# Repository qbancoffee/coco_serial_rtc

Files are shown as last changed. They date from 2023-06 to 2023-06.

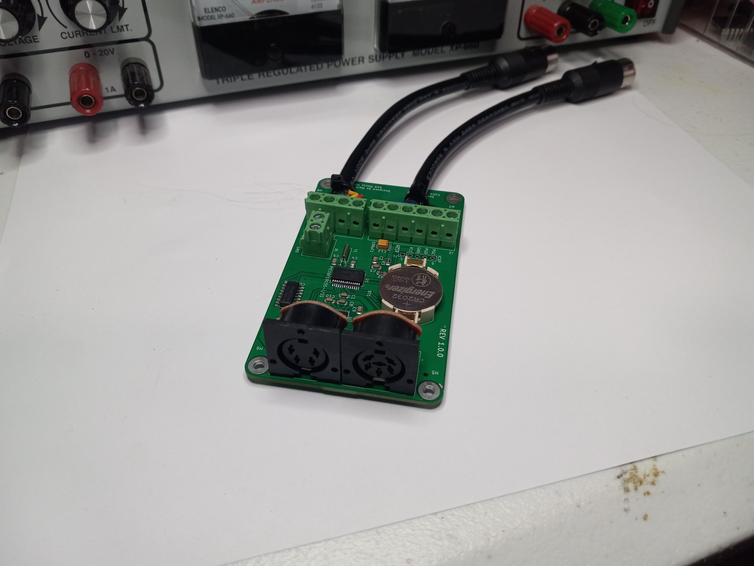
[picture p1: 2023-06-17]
images/coco_serial_rtc_assembled_3.jpg

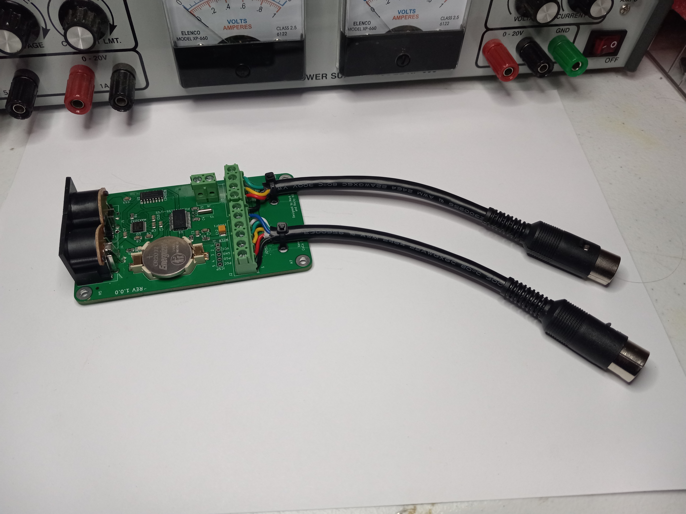
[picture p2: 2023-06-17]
images/coco_serial_rtc_assembled_2.jpg

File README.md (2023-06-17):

# coco_serial_rtc
An external Real Time Clock circuit (RTC) for the Tandy CoCo.

This is a realtime clock prototype for the Tandy CoCo. The board connects to the CoCo's bit banger serial port via a male DIN connector pigtail.
Whith the appropriate commands from the CoCo, one can get the date/time or one can set the date/time. The rest of the time it just sits in place and works as a serial passthrough so that you can still connect other serial devices to the CoCo. The other serial devices can connect to the onboard DIN connector. The board requires +5V DC and can be powered from the CoCo's joystick port or one can provide the voltage to a 2 pin terminal strip. The board also serves a passthrough when using the joystick port.

The board was designed using KiCAD 6 and the firmware was written in C and compiled with the [CCS C Compiler](https://www.ccsinfo.com/compilers.php).

## CoCo Serial RTC
- [Schematic](coco_serial_rtc_schematic.pdf)
- [Rendered Image](images/coco_serial_rtc_top.png)
- [Picture 1](images/coco_serial_rtc.jpg)
- [Picture 2](images/coco_serial_rtc_assembled_1.jpg)
- [Picture 3](images/coco_serial_rtc_assembled_2.jpg)
- [Picture 4](images/coco_serial_rtc_assembled_3.jpg)

## How it works
Add stuff here.

### Current status
- [x] Ordered
- [x] Assembled
- [x] Testing

The board is still in the prototype stage but so far things are looking good.

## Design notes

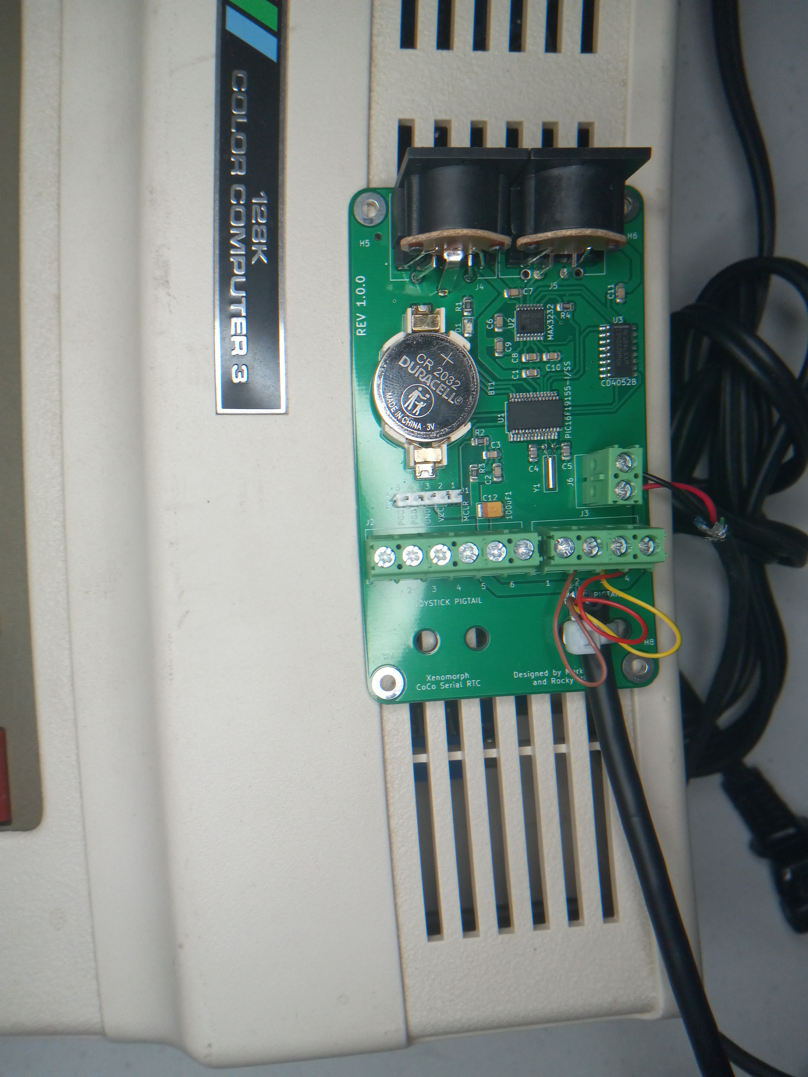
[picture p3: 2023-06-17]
images/coco_serial_rtc.jpg

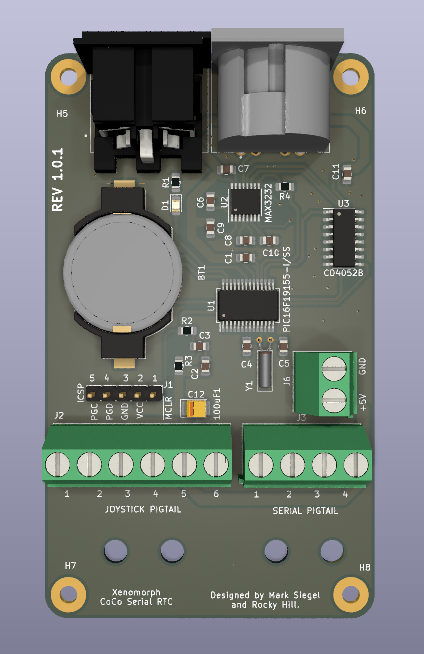
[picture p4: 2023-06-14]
images/coco_serial_rtc_top.png

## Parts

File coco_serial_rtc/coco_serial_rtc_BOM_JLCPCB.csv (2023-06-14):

Qty | Designator | Footprint | Vendor | Vendor part# | Manufacturer part# | Value | LibPart | Datasheet | Manufacturer part# | Vendor | Vendor part# | manufacturer part# | vendor | vendor part#
1 | C12 | Capacitor_Tantalum_SMD:CP_EIA-3528-21_Kemet-B_Pad1.50x2.35mm_HandSolder | LCSC | C16133 | TAJB107K006RNJ | C_Polarized_Small | Device:C_Polarized_Small | https://datasheet.lcsc.com/lcsc/2111161030_Kyocera-AVX-TAJB107K006RNJ-_C16133.pdf | TAJB107K006RNJ | LCSC | C16133
1 | BT1 | Battery:BatteryHolder_Keystone_1058_1x2032 | LCSC | C964770 | BS-06-B4AA015 | CR2032 | Device:Battery_Cell | https://datasheet.lcsc.com/lcsc/2012311835_MYOUNG-BS-06-B4AA015_C964770.pdf | BS-06-B4AA015 | LCSC | C964770
9 | C1, C2, C3, C6, C7, C8, C9, C10, C11 | Capacitor_SMD:C_0805_2012Metric_Pad1.18x1.45mm_HandSolder | LCSC | C49678 | CC0805KRX7R9BB104 | .1uF | Device:C_Small | https://datasheet.lcsc.com/lcsc/1810101813_YAGEO-CC0805KRX7R9BB104_C49678.pdf | CC0805KRX7R9BB104 | LCSC | C49678
2 | C4, C5 | Capacitor_SMD:C_0805_2012Metric_Pad1.18x1.45mm_HandSolder | LCSC | C1804 | CL21C220JBANNNC | 22pF | Device:C_Small | https://datasheet.lcsc.com/lcsc/1810271113_Samsung-Electro-Mechanics-CL21C220JBANNNC_C1804.pdf | CL21C220JBANNNC | LCSC | C1804
1 | D1 | LED_SMD:LED_0805_2012Metric_Pad1.15x1.40mm_HandSolder | LCSC | C2296 | 17-21SUYC/TR8 | LED | Device:LED | https://datasheet.lcsc.com/lcsc/1806151129_Hubei-KENTO-Elec-17-21SUYC-TR8_C2296.pdf | 17-21SUYC/TR8 | LCSC | C2296
4 | H1, H2, H3, H4 | MountingHole:MountingHole_4mm |  | DNI | DNI | MountingHole | Mechanical:MountingHole | ~
4 | H5, H6, H7, H8 | MountingHole:MountingHole_3mm_Pad |  | DNI | DNI | MountingHole | Mechanical:MountingHole | ~
1 | J1 | Connector_PinHeader_2.54mm:PinHeader_1x05_P2.54mm_Vertical |  | DNI | DNI | ICSP | Connector:Conn_01x05_Male | ~
1 | J2 | TerminalBlock_Phoenix:TerminalBlock_Phoenix_MKDS-1,5-6_1x06_P5.00mm_Horizontal | digikey | DNI | DNI | joystick terminal | Connector:Screw_Terminal_01x06 | https://media.digikey.com/pdf/Data%20Sheets/Phoenix%20Contact%20PDFs/1935161.pdf | 1935161 | digikey | 277-1667-ND
1 | J3 | TerminalBlock_Phoenix:TerminalBlock_Phoenix_MKDS-1,5-4_1x04_P5.00mm_Horizontal | digikey | DNI | DNI | serial terminal | Connector:Screw_Terminal_01x04 | https://media.digikey.com/pdf/Data%20Sheets/Phoenix%20Contact%20PDFs/1935161.pdf | 1935161 | digikey | 277-1667-ND
1 | J4 | serial_rtc.kicad:CUI_SDS-60J | digikey | DNI | DNI | DIN-6 | serial_rtc:DIN-6-Connector | http://www.mouser.com/ds/2/18/40_c091_abd_e-75918.pdf | SDS-60J | digikey | CP-2360-ND
1 | J5 | serial_rtc.kicad:CUI_SDS-40J | digikey | DNI | DNI | DIN-4 | serial_rtc:DIN-4-Connector | https://www.cuidevices.com/product/resource/digikeypdf/sds-j.pdf | SDS-40J | digikey | CP-2340-ND
1 | J6 | TerminalBlock_Phoenix:TerminalBlock_Phoenix_MKDS-1,5-2_1x02_P5.00mm_Horizontal | digikey | DNI | DNI | power terminal | Connector:Screw_Terminal_01x02 | https://media.digikey.com/pdf/Data%20Sheets/Phoenix%20Contact%20PDFs/1935161.pdf | 1935161 | digikey | 277-1667-ND
1 | R1 | Resistor_SMD:R_0805_2012Metric_Pad1.20x1.40mm_HandSolder | LCSC |  |  | 330 | Device:R_Small_US | ~ |  | LCSC
1 | R2 | Resistor_SMD:R_0805_2012Metric_Pad1.20x1.40mm_HandSolder | LCSC | C17540 | 0805W8F2000T5E | 200 | Device:R_Small_US | https://datasheet.lcsc.com/lcsc/2206010200_UNI-ROYAL-Uniroyal-Elec-0805W8F2000T5E_C17540.pdf | 0805W8F2000T5E | LCSC | C17540
1 | R3 | Resistor_SMD:R_0805_2012Metric_Pad1.20x1.40mm_HandSolder | LCSC | C17414 | 0805W8F1002T5E | 10K | Device:R_Small_US | https://datasheet.lcsc.com/lcsc/2206010216_UNI-ROYAL-Uniroyal-Elec-0805W8F1501T5E_C4310.pdf | 0805W8F1002T5E | LCSC | C17414
1 | R4 | Resistor_SMD:R_0805_2012Metric_Pad1.20x1.40mm_HandSolder | LCSC | C17710 | 0805W8F4700T5E | 470 | Device:R_Small_US | https://datasheet.lcsc.com/lcsc/2206010200_UNI-ROYAL-Uniroyal-Elec-0805W8F4700T5E_C17710.pdf | 0805W8F4700T5E | LCSC | C17710
1 | U1 | Package_SO:SSOP-28_5.3x10.2mm_P0.65mm | digikey | DNI | DNI | PIC16F19155-I/SS | serial_rtc:PIC16F19155-I{slash}SS | https://ww1.microchip.com/downloads/en/DeviceDoc/PIC16LF19155-56-75-76-85-86-Data-Sheet-40001923B.pdf | PIC16F19155-I/SS | digikey | PIC16F19155-I/SS-ND
1 | U2 | Package_SO:TSSOP-16-1EP_4.4x5mm_P0.65mm | LCSC | C19767 | MAX3232EUE+T | MAX3232 | Interface_UART:MAX3232 | http://www.ti.com/general/docs/suppproductinfo.tsp?distId=10 | MAX3232EUE+T | LCSC | C19767
1 | U3 | Package_SO:SOIC-16_3.9x9.9mm_P1.27mm | LCSC | C6521 | CD4052BM96 | CD4052B | Analog_Switch:CD4052B | http://www.ti.com/lit/ds/symlink/cd4052b.pdf | CD4052BM96 | LCSC | C6521
1 | Y1 | Crystal:Crystal_C26-LF_D2.1mm_L6.5mm_Horizontal | digikey | DNI | DNI | 32.768kHz | Device:Crystal | http://cfd.citizen.co.jp/cms/cfd/pdf/english/CFS-206_CFS-145_E.pdf |  |  |  | CFS-20632768DZBB | digikey | 300-8301-ND

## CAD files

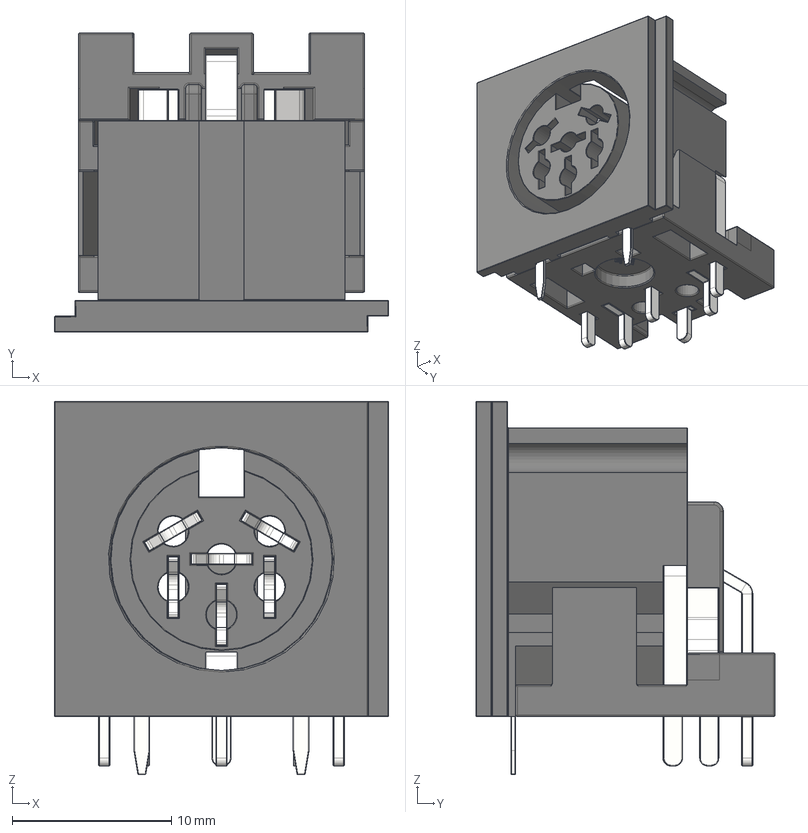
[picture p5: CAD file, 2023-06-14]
coco_serial_rtc/3d_models/DIN-6.step
21.0 x 18.8 x 23.4 mm
Baseplate IEC
Pin3
Pin4_2
Pin5_1
Pin6
Gnd pins
Housing

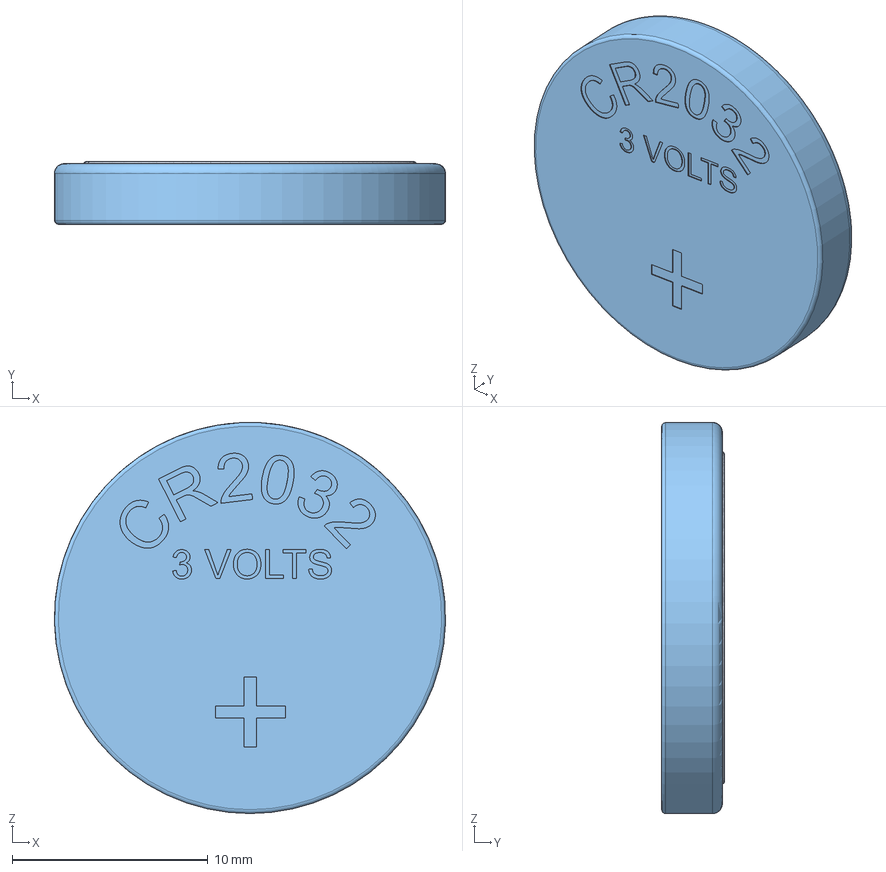
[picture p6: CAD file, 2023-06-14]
coco_serial_rtc/3d_models/CR2032-50004LC.stp
20.0 x 3.20 x 20.0 mm

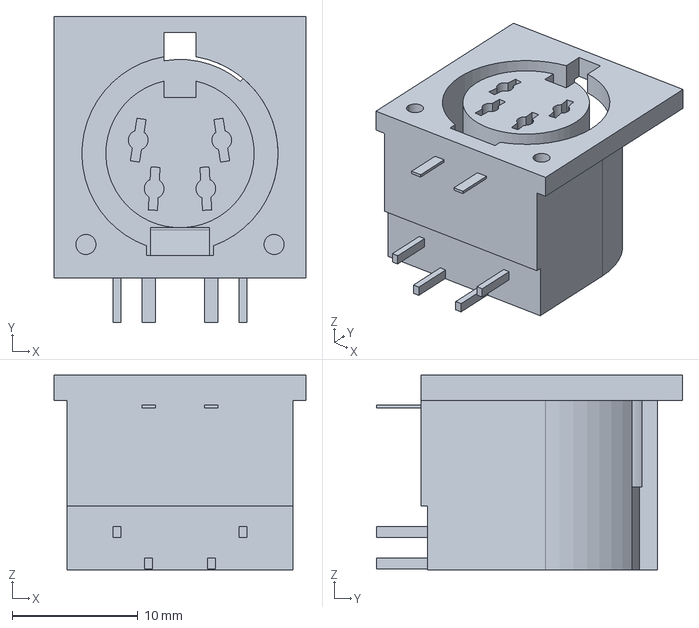
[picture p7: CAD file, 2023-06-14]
coco_serial_rtc/3d_models/DIN-4.stp
20.1 x 24.4 x 15.5 mm

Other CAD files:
coco_serial_rtc/Unnamed-coco_serial_rtc.stl

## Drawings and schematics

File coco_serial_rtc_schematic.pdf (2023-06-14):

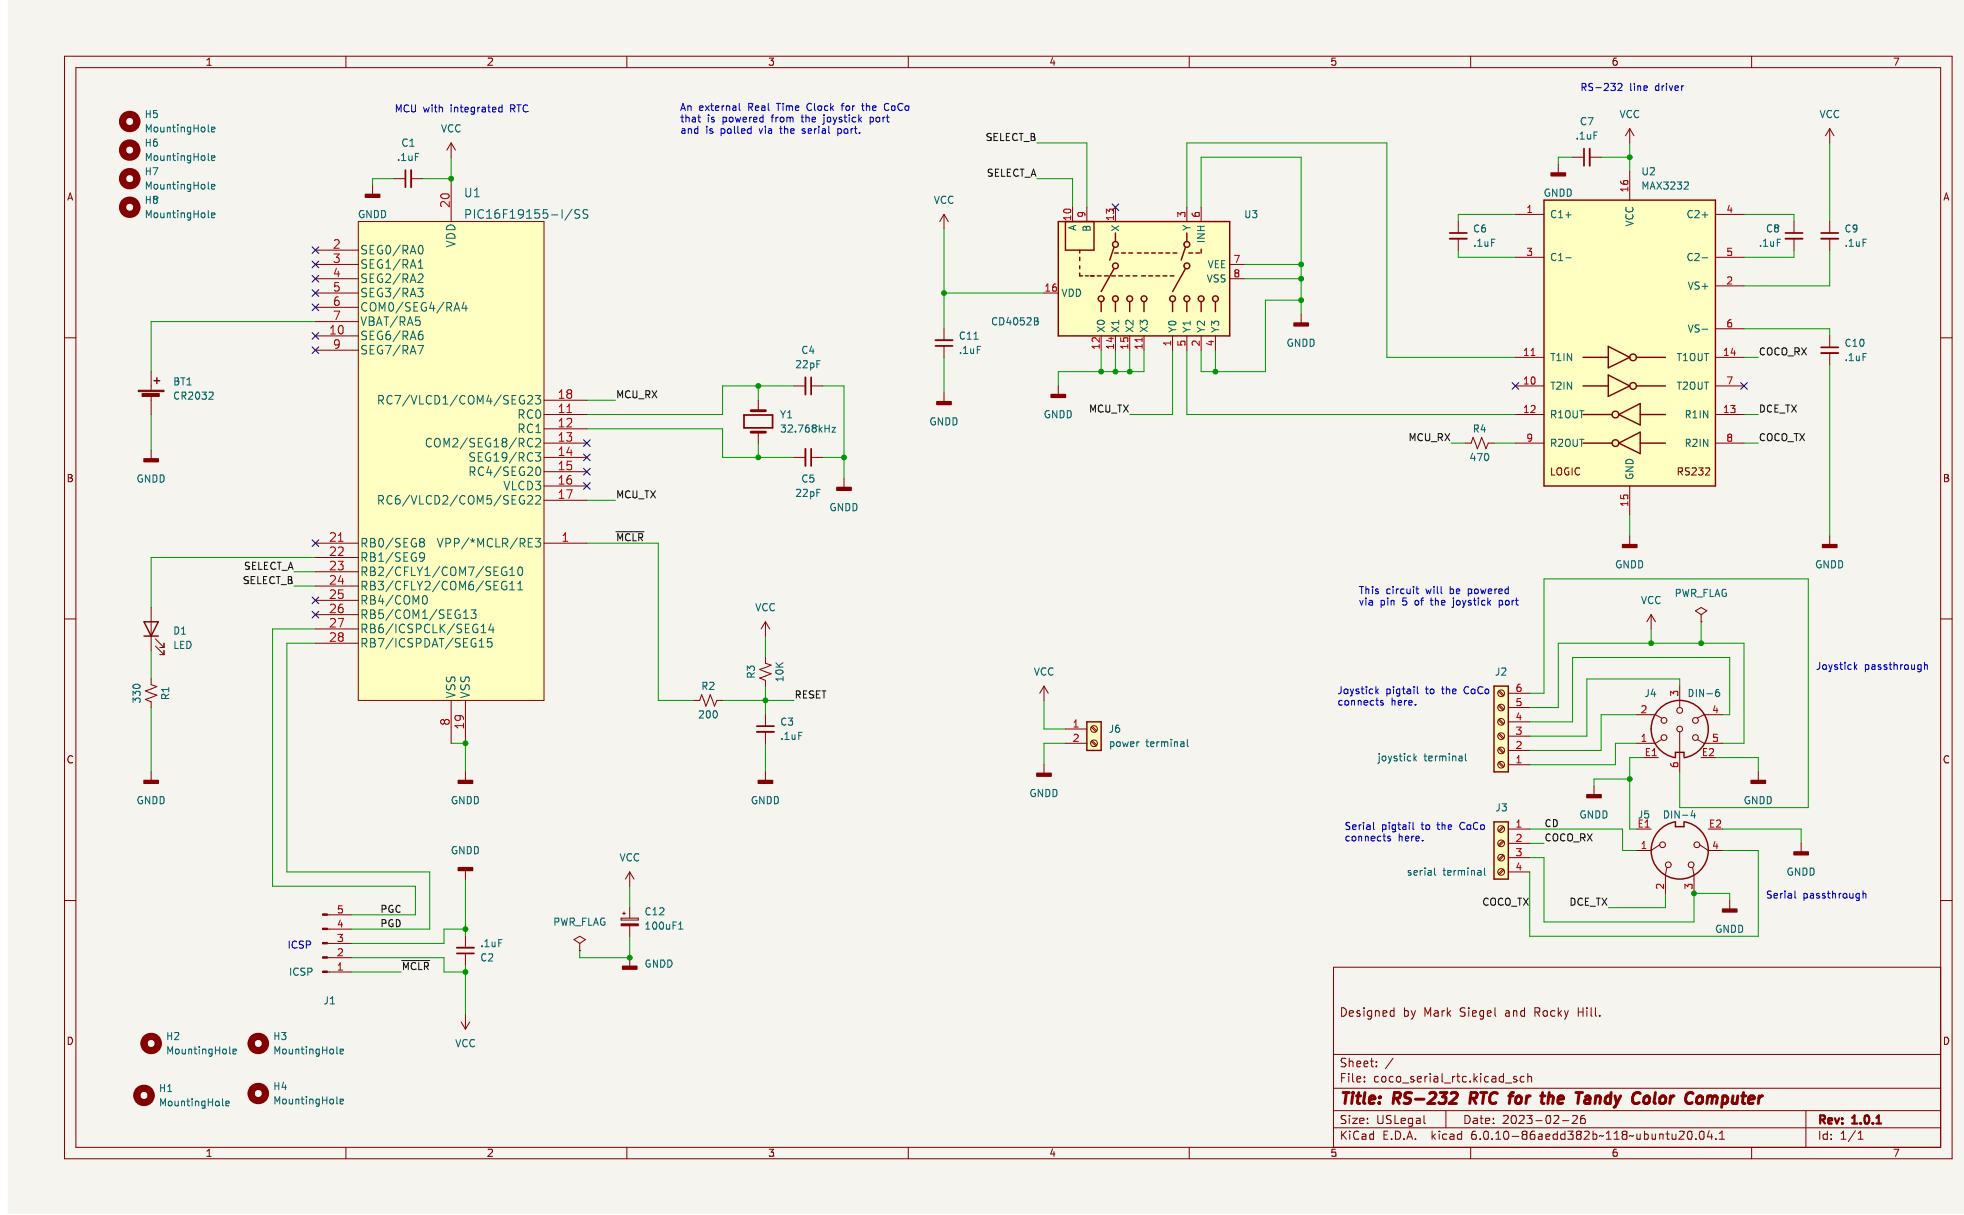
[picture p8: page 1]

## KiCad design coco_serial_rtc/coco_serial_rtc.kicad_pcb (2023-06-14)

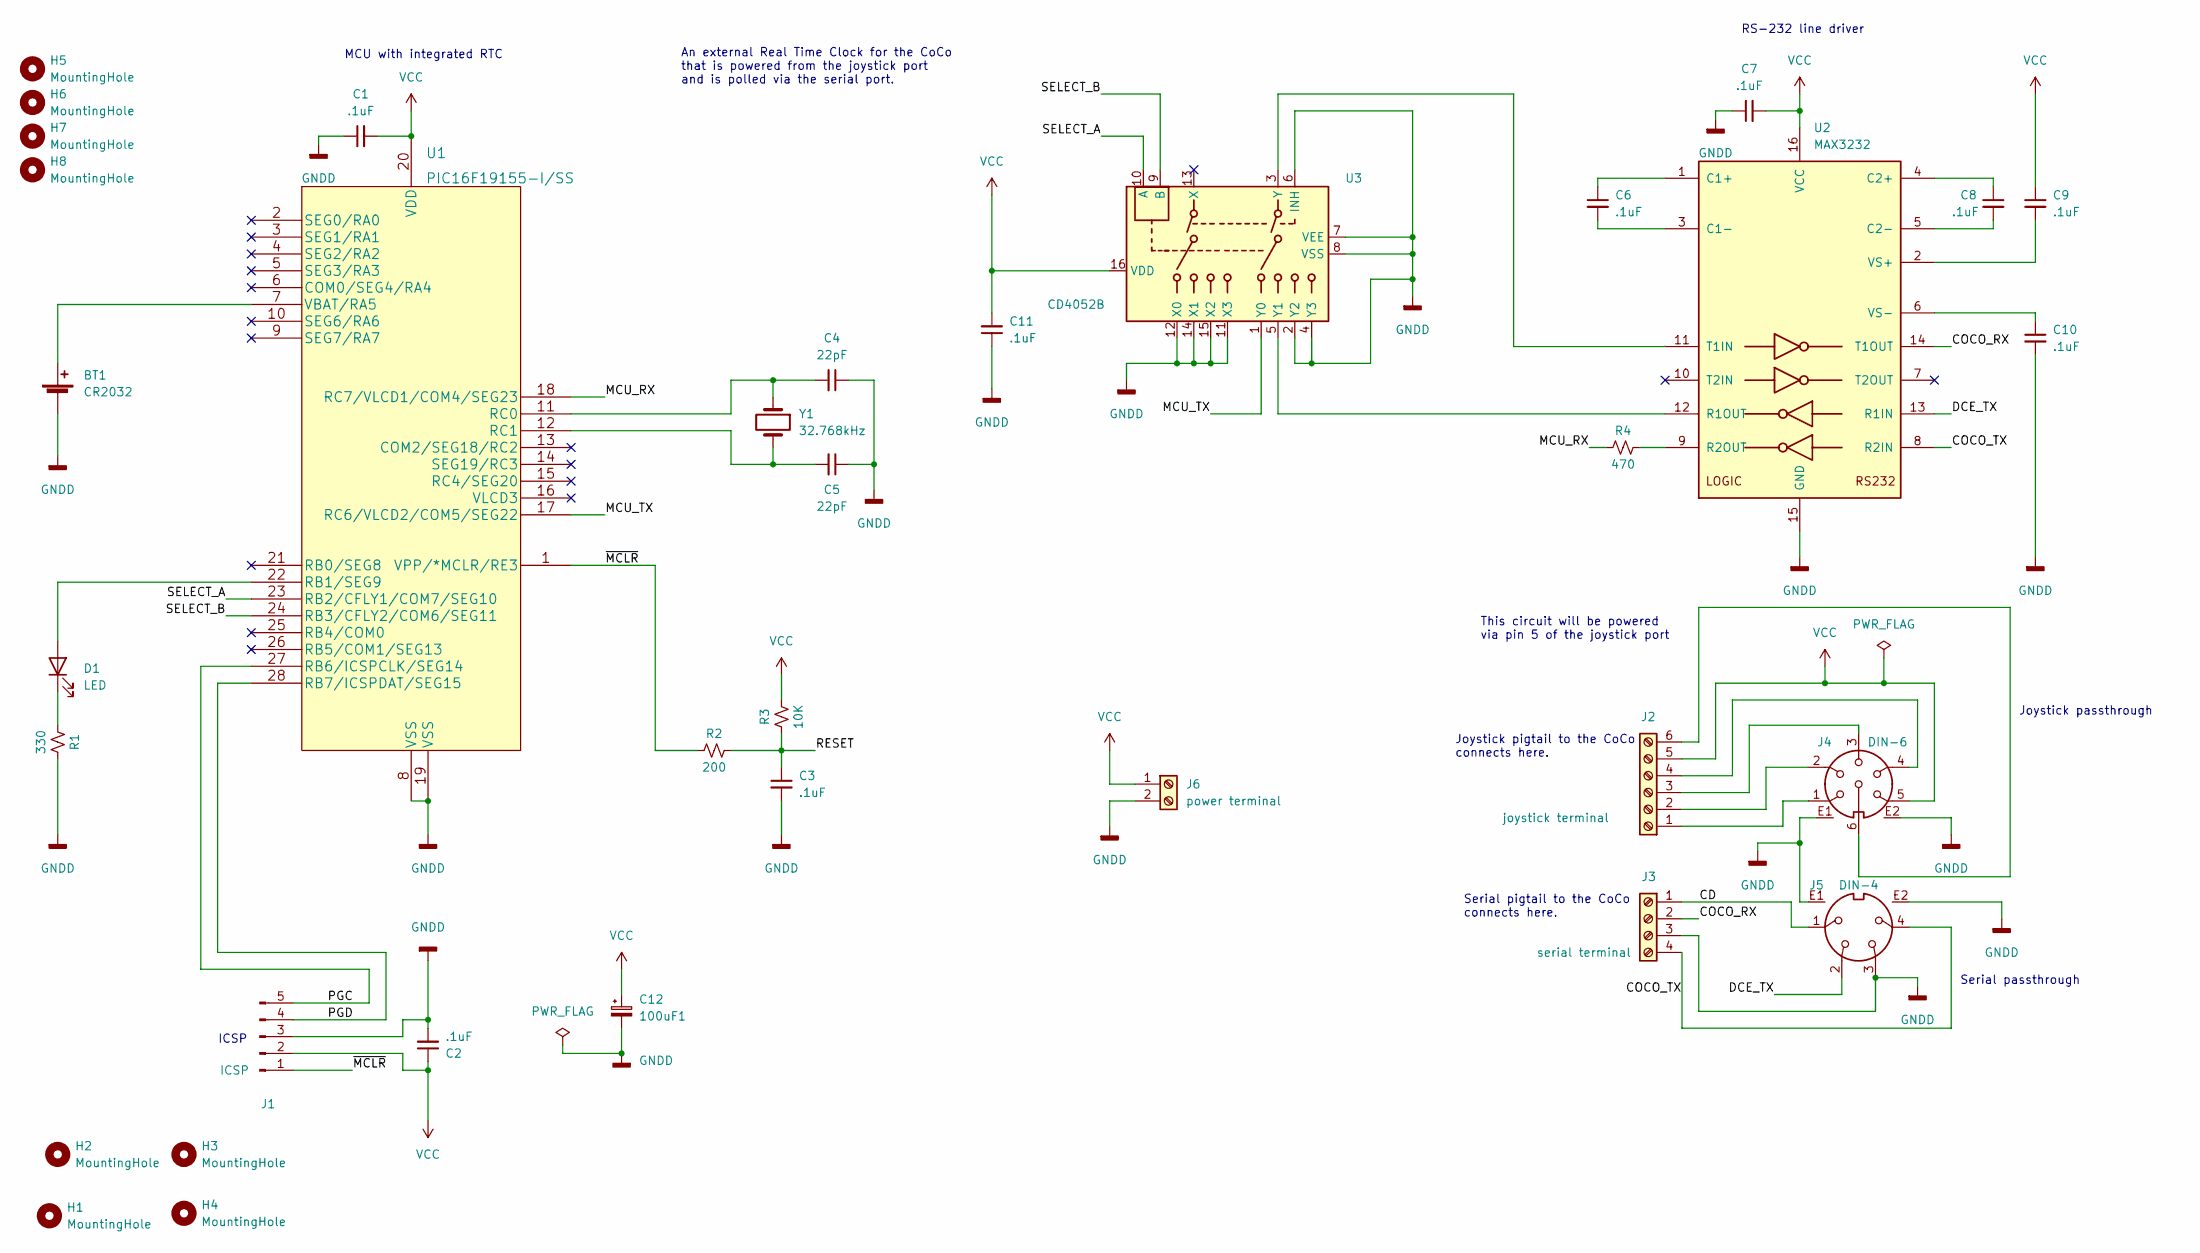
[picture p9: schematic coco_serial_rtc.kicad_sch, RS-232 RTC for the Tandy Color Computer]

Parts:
BT1: CR2032; BatteryHolder_Keystone_1058_1x2032; Manufacturer part# BS-06-B4AA015
C1, C2, C3, C6, C7, C8, C9, C10, C11: .1uF; C_0805_2012Metric_Pad1.18x1.45mm_HandSolder; Manufacturer part# CC0805KRX7R9BB104
C4, C5: 22pF; C_0805_2012Metric_Pad1.18x1.45mm_HandSolder; Manufacturer part# CL21C220JBANNNC
C12: 100uF1; CP_EIA-3528-21_Kemet-B_Pad1.50x2.35mm_HandSolder; Manufacturer part# TAJB107K006RNJ
D1: LED; LED_0805_2012Metric_Pad1.15x1.40mm_HandSolder; Manufacturer part# 17-21SUYC/TR8
H1, H2, H3, H4: MountingHole; MountingHole_4mm
H5, H6, H7, H8: MountingHole; MountingHole_3mm_Pad
J1: ICSP; PinHeader_1x05_P2.54mm_Vertical
J2: joystick terminal; TerminalBlock_Phoenix_MKDS-1,5-6_1x06_P5.00mm_Horizontal; Manufacturer part# 1935161
J3: serial terminal; TerminalBlock_Phoenix_MKDS-1,5-4_1x04_P5.00mm_Horizontal; Manufacturer part# 1935161
J4: DIN-6; CUI_SDS-60J; Manufacturer part# SDS-60J
J5: DIN-4; CUI_SDS-40J; Manufacturer part# SDS-40J
J6: power terminal; TerminalBlock_Phoenix_MKDS-1,5-2_1x02_P5.00mm_Horizontal; Manufacturer part# 1935161
R1: 330; R_0805_2012Metric_Pad1.20x1.40mm_HandSolder
R2: 200; R_0805_2012Metric_Pad1.20x1.40mm_HandSolder; Manufacturer part# 0805W8F2000T5E
R3: 10K; R_0805_2012Metric_Pad1.20x1.40mm_HandSolder; Manufacturer part# 0805W8F1002T5E
R4: 470; R_0805_2012Metric_Pad1.20x1.40mm_HandSolder; Manufacturer part# 0805W8F4700T5E
U1: PIC16F19155-I/SS; SSOP-28_5.3x10.2mm_P0.65mm; Manufacturer part# PIC16F19155-I/SS
U2: MAX3232; TSSOP-16-1EP_4.4x5mm_P0.65mm; Manufacturer part# MAX3232EUE+T
U3: CD4052B; SOIC-16_3.9x9.9mm_P1.27mm; Manufacturer part# CD4052BM96
Y1: 32.768kHz; Crystal_C26-LF_D2.1mm_L6.5mm_Horizontal; Manufacturer part# CFS-20632768DZBB

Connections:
/CD: J3.1, J5.1
/COCO_RX: J3.2, U2.14 (T1OUT)
/COCO_TX: J3.4, J5.4, U2.8 (R2IN)
/DCE_TX: J5.2, U2.13 (R1IN)
/MCU_RX: R4.1, U1.18 (RC7/VLCD1/COM4/SEG23)
/MCU_TX: U1.17 (RC6/VLCD2/COM5/SEG22), U3.1 (Y0)
/PGC: J1.5, U1.27 (RB6/ICSPCLK/SEG14)
/PGD: J1.4, U1.28 (RB7/ICSPDAT/SEG15)
/RESET: C3.1, R2.2, R3.1
/SELECT_A: U1.23 (RB2/CFLY1/COM7/SEG10), U3.10 (A)
/SELECT_B: U1.24 (RB3/CFLY2/COM6/SEG11), U3.9 (B)
/~MCLR: J1.1, R2.1, U1.1 (VPP/*MCLR/RE3)
GNDD: BT1.2 (-), C1.1, C2.2, C3.2, C4.1, C5.1, C7.1, C10.2, C11.1, C12.2, J1.3, J3.3, J4.E1, J4.E2, J5.3, J5.E1, J5.E2, J6.2, R1.2, U1.8 (VSS), U1.19 (VSS), U2.15 (GND), U3.2 (Y2), U3.4 (Y3), U3.6 (INH), U3.7 (VEE), U3.8 (VSS), U3.11 (X3), U3.12 (X0), U3.14 (X1), U3.15 (X2)
unnamed: BT1.1 (+), U1.7 (VBAT/RA5)
unnamed: C4.2, U1.11 (RC0), Y1.1
unnamed: C5.2, U1.12 (RC1), Y1.2
unnamed: C6.1, U2.1 (C1+)
unnamed: C6.2, U2.3 (C1-)
unnamed: C8.1, U2.4 (C2+)
unnamed: C8.2, U2.5 (C2-)
unnamed: C9.2, U2.2 (VS+)
unnamed: C10.1, U2.6 (VS-)
unnamed: D1.1 (K), R1.1
unnamed: D1.2 (A), U1.22 (RB1/SEG9)
unnamed: J2.1, J4.1
unnamed: J2.2, J4.2
unnamed: J2.3, J4.3
unnamed: J2.4, J4.4
unnamed: J2.6, J4.6
unnamed: R4.2, U2.9 (R2OUT)
unnamed: U2.11 (T1IN), U3.3 (Y)
unnamed: U2.12 (R1OUT), U3.5 (Y1)
VCC: C1.2, C2.1, C7.2, C9.1, C11.2, C12.1, J1.2, J2.5, J4.5, J6.1, R3.2, U1.20 (VDD), U2.16 (VCC), U3.16 (VDD)

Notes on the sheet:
RS-232 line driver
An external Real Time Clock for the CoCo that is powered from the joystick port and is polled via the serial port.
Joystick passthrough
MCU with integrated RTC
Joystick pigtail to the CoCo connects here.
This circuit will be powered via pin 5 of the joystick port
ICSP
Serial pigtail to the CoCo connects here.
Serial passthrough

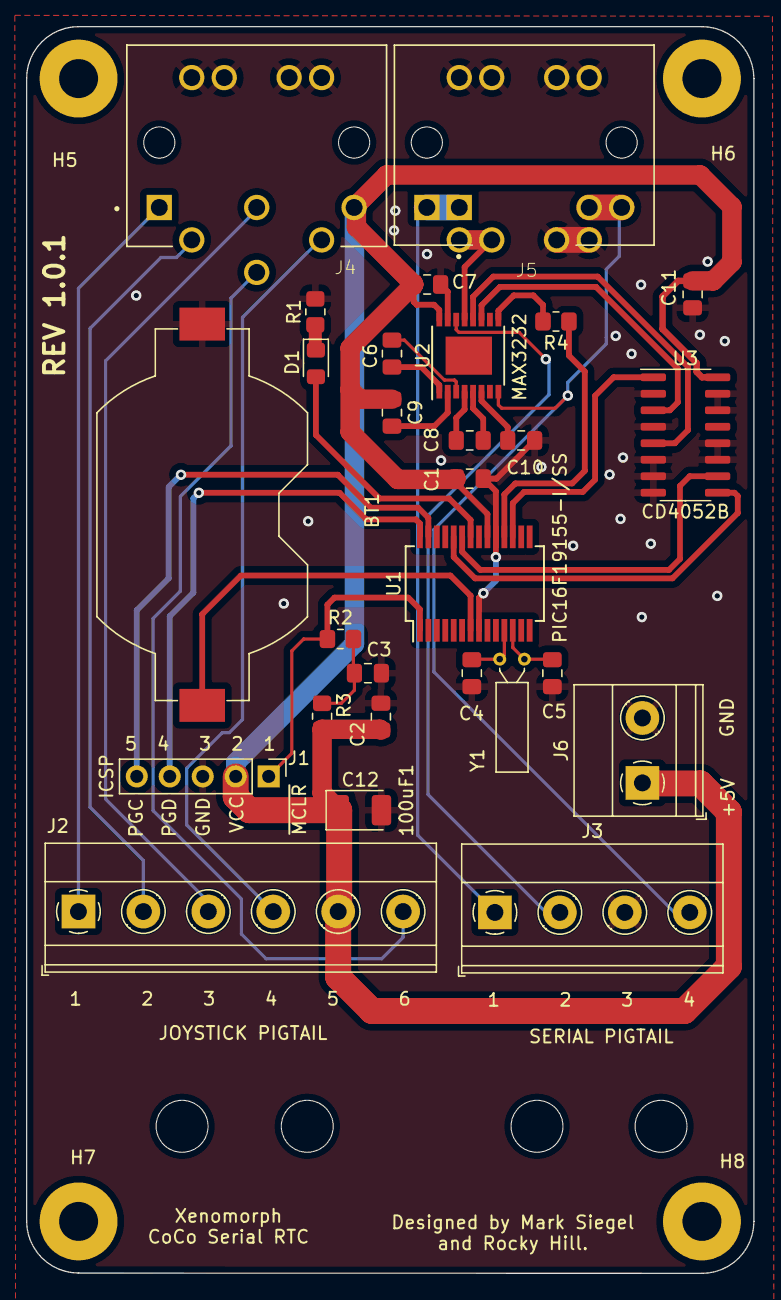
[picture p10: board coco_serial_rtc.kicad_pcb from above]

Board: 2 copper layers, 56.0 x 96.0 mm, 36 parts (0 on the bottom side), 33 nets.

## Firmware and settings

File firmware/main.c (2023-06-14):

//*************************************
//* <16F19155.h> processor
//* Date: 3/27/2023
//* Ver. 0.9
//* by M D Siegel
//*
//* Copyright 2023  M D SIEGEL
//* All Rights Reserved
//* Last updated 3/31/2023
//**************************************
  #include <main.h>
  #include <ctype.h>
  #include <stdio.h>
  #include <stddef.h>
  #include <stdlib.h>
  #include <string.h>

   //RTCC
  rtc_time_t wizardTempTime;
////////////////////////////////////////
// Pic 16F19155 Picdem 2 plus
// B1       LED
// B2       SELA
// B3       SELB
// C7       RX
// C6       TX
// B6       PGC
// B7       PGD
// E3       MCLR
// C0-C1    Crystal
///////////////////// Global Vars

static int cntdown;


char xstring1[20];
char xstring2[5];
//char xstring3[5];
char xstring4[7];
char pls[2] ="+";
char slp[6] ="SLEEP";
const char paramname[] [6]= {"VER","SDATE","STIME","RDT","MODE","PEEK","POKE","HELP",""""};

static int parsenum; //result of compair
static int parsetype; // operator
static int16 parseval; // val to set
static int split[8];
static char *pbuffer;
char rbuff[8];
static char compbuff[20];
static int buflen;
static char rs232buff[81];
static char rsreadbuff[81];
static int rsptr;
static int rtflag;
static int blenq;
static int16 aboo; //debug
char temp;

STATIC int16 ADC_BT;     // battery

///////////////////////Defines
#define LED PIN_B1   //LED
#define SELA PIN_B2
#define SELB PIN_B3
#define RX PIN_C7
#define TX PIN_C6

#define parseitm 9

#pin_select U1RX=PIN_C7

#use rs232(baud=1200,parity=N,xmit=PIN_C6,rcv=PIN_C7,bits=8,stream=DATA)

////////////// Functions
void copyright(void);
void  RTC_isr(void);
void  RDA_isr(void);
void  TIMER0_isr(void);

int read232(void);   // RS232
int is_rs232(void);
void clrprbuff(void);
void clrrsbuff(void);
int parseit(char * buf1,int clen);
char * strpiece(int pieceNum,int clen, char *buf1);
int compit(char *buf1, char *buf2, int clen);
int process(void);
void set_clock(void);
void read_clock(void);
void chan_sel(int chanx);
void updateADC();
void xsetDate();
void xsetTime();
void qsleep();
void xpoke();

////////////// code
#INT_TIMER0
void  TIMER0_isr(void) 
{
cntdown--;
   
   if(cntdown <= 0)
   { output_toggle(LED);
      cntdown = 60;
   }
    clear_interrupt(int_timer0);
}

#INT_RDA
void  RDA_isr(void) 
{
//! temp = fgetc(DATA);       //get char
//!       printf("*");
//!       rs232buff[rsptr++]=temp;  //inc buffer
//!       if (rsptr >= 79)          //max buffer
//!         {
//!            rsptr = 79;
//!         }
//!       if((temp == 0x0D))
//!       {
//!         temp = 0x0A;
//!         
//!       }
//!      
//!       if((temp == 0x0A))        //cr
//!         {
//!         
//!            if(rsptr >= 3)       //valid buffer process
//!            {
//!               rtflag = 1;
//!            }
//!            else
//!            {
//!               rsptr = 0;       //invalid buffer restart 
//!            }
//!          }
//!      
//! clear_interrupt(int_rda);
}

#INT_RTC
void  RTC_isr(void) 
{

}

void main()
{
    int16 wtmp, i, cmdsta;
    
   setup_adc_ports(0x3A);
   setup_adc(ADC_CLOCK_INTERNAL);
   setup_timer_0(RTCC_INTERNAL|RTCC_DIV_64|RTCC_8_BIT);      //2.0 ms overflow
   
   //RTCC
   setup_rtc(RTC_ENABLE|RTC_CLOCK_SOSC,0);
   enable_interrupts(INT_TIMER0);
   //enable_interrupts(INT_RDA);
   enable_interrupts(INT_RTC);
   enable_interrupts(GLOBAL);
   
   
   chan_sel(0);
   cntdown = 60;
   
   printf(" ***\n\r");
   printf("Coco RTC Command Processor Active \n\r");
   
   while(TRUE)
   {
      
      if(kbhit())
      {
      temp = fgetc(DATA);       //get char
       rs232buff[rsptr++]=temp;  //inc buffer
       if (rsptr >= 79)          //max buffer
         {
            rsptr = 79;
         }
       if((temp == 0x0D))
       {
         temp = 0x0A;
         
       }
      
       if((temp == 0x0A))        //cr
         {
         
            if(rsptr >= 3)       //valid buffer process
            {
               rtflag = 1;
            }
            else
            {
               rsptr = 0;       //invalid buffer restart 
            }
          }
      }
//////////////RS232 Process Terminal Loop
      if(is_rs232() == 1)
      {
       blenq = read232();
                           //printf("len %i buff %s \n\r",blenq,rs232buff );
      clrrsbuff();
        
      wtmp =  parseit(rsreadbuff, sizeof(rsreadbuff)); 
      pbuffer = strpiece(split[0], 20, rsreadbuff);   //Parse input
                           //printf("part1: %s \n\r",pbuffer);
     
     for(i=0;i<=parseitm;i++)                               //Compair to table
      { 
         sprintf(compbuff,"%s",paramname[i]);
         parsenum = strcmp(compbuff, pbuffer);
         if (parsenum==0)
         {
                           //printf("parse # %i \n\r",i);
            parsenum = i;
            break;
         }
         if(i == 19)
         {
         parsenum = i;
         }
                        //printf("parse # %i \n\r",i); 
      }
      ///////////////////
      pbuffer = 35;
      pbuffer = strpiece(split[1], 20, rsreadbuff);   //Parse function type
      if(*pbuffer == 35) //#
         {
         parsetype = 0;
         }
      if(*pbuffer == 63) //? return return
         {
         parsetype = 1;
         }
      if(*pbuffer == 61) //= set var
         {
         parsetype = 2;
         }
                        //printf("part2: %s \n\r",pbuffer);
      strcpy(xstring1,pbuffer);
                        //printf("parse type %i \n\r",parsetype);
      
      pbuffer = 0;
      pbuffer = strpiece(split[2], 20, rsreadbuff);  //Parse Parm
                     //parseval = atoi(pbuffer);
      
      if(parsetype == 2)
      {
     
      pbuffer = strpiece(split[2], 20, rsreadbuff);
      
                    //printf("str buff: %s \n\r",pbuffer);
      strcpy(rbuff,pbuffer);
      parseval = atol(rbuff);
      
                  //printf("part3: %Ld \n\r",parseval);
      }
      if(parsenum <= parseitm)
      {
                  //printf("parse # %i \n\r",parsenum);
      cmdsta = process(); //Process Command
      }
      else
      {
         printf("syntax error\n\r");
      }
      clrprbuff();
      rtflag = 0;
      rsptr=0;
   }
   ////////// End rs232
      //TODO: User Code
   }
     
}
////////////////////////////////////////////
// Select rs232 TX channel 0 - 3
void chan_sel(int chanx)
{
      output_low(SELA);
      if((chanx & 1) == 1)
      {
      output_high(SELA);
      }
      
       output_low(SELB);
      if(((chanx >> 1) & 1) == 1)
      {
      output_high(SELB);
      }
}
/////////////////////////////////////////////// Battery div 3
void updateADC()
{
   int done;
   set_adc_channel (0x3A) ;
   delay_us (6);
   read_adc (ADC_START_ONLY) ; 
   done = adc_done ();
   WHILE ( !done)
   {
      done = adc_done();
   }
   
   ADC_BT = read_adc (ADC_READ_ONLY);
}
//////////////////////////////////////////////
void copyright()
{
   char one[1];
   BYTE CONST TABLE [25] = {"Copyright2023 MD SIEGEL"};
   one[0] = TABLE[0];
}
////////////////////////////
int read232()
{
   int df;
   buflen = rsptr - 2;
   
   clrprbuff();    // clear copy to buff
   if(buflen > 0)
   {
     for (df = 0; df <= buflen; df++)
     {
     rsreadbuff[df] = rs232buff[df]; // copy buffer
     }
  
  for (df = 0; df <= 81; df++)
  {
     if (rs232buff[df] > 126)  // Filter buffer
     {
      rs232buff[df] = 32;
     }
   }
   
   }
   return (buflen);
}
int is_rs232()
{
   return(rtflag); // return ready to process
}
void clrprbuff() // Clear serial input buffer
{  int i;
   for(i=0;i<=81;i++)
   {
   rsreadbuff[i]=0;
   }
}
void clrrsbuff() // Clear rs232 input buffer
{  int i;
   for(i=0;i<=80;i++)
   {
   rs232buff[i]=0;
   }
}
//////////////////// split string
int parseit(char * buf1, int clen) // Parse Cgarater String input
{
   int parsecnt,cindx,cflag,cli;
   char tmpz;
   parsecnt = 0;
   cflag = 0;
   for(cli = 0;cli <=8;cli++)
   {
   split[cli] = 0;
   }
   for(cindx = 0;cindx <= clen;cindx++)
   {
      tmpz = *(buf1 + cindx);
      if (tmpz == 0)
      {
         return(parsecnt);
      }
      if ((tmpz != 0x20)&(cflag == 0)) // look for space or 0 char
      {
         cflag = 1;
         split[parsecnt] = cindx;
         parsecnt++;
      }
      if (tmpz == 0x20)
      {
         cflag = 0;
      }
   }
}
/////////////////////////// get parm pos
char * strpiece(int pieceNum,int clen, char *buf1) // get parse piece
{
   int cindx;
   char tmpz;
   char tchr[20];
   for(cindx = 0;cindx <=20;cindx++)
   {
   tchr[cindx]=0;
   }
   for (cindx = 0; cindx <= clen; cindx++)
   {
      tmpz = *(buf1 +pieceNum + cindx);
      if((tmpz == 0x20)|(tmpz == 0))
      {
         
         return((char *) tchr);
      }
      tchr[cindx] = tmpz;
   }
   return((char *) tchr);
}

////////////////// compair return
int compit(char *buf1, char *buf2, int clen) // compair to table
{
   int i;
   char tmpz,tmpx;
    
   for (i=0; i <=clen;i++)
   {
      tmpz = *(buf1 +i);
      tmpx = *(buf2 +i);
      if((tmpz == 0)&(tmpx == 0))
      {
      return(1);
      }

      if(tmpz != tmpx)
      {
         return(0);
      }
   }
   return(1);
}
////////////////////////////////// Process terninal input
int process()
{
   int xret;
   xret = 0;
    // printf("sa #%s\n\r",xstring1);
   switch (parsenum) {

    case 0: // VER
           if(parsetype==0)
            {
            printf("VER 0.2 ");
            updateADC();
            if(ADC_BT <= 735)
            {  printf("BATT <LOW>\n\r");}
            else
            {printf("BATT <GOOD>\n\r");}
           
            }
           break;

    case 1: // SDATE
           if(parsetype==0)
            {
             xsetDate();
            }

           break;
    
    case 2: // STIME
           if(parsetype==0)
            {
            xsetTime();
            }

           break;
           
    case 3: //RDT
           if(parsetype==0)
            {
               rtc_read(&wizardTempTime);
               
                printf("%02u/%02u/20%02u %02u:%02u:%02u\n\r",wizardTempTime.tm_mon,wizardTempTime.tm_mday,wizardTempTime.tm_year,wizardTempTime.tm_hour,wizardTempTime.tm_min,wizardTempTime.tm_sec);

            }
           break;
           
    case 4: //MODE
           if(parsetype==0)
            {
             if(!strcmp(slp,xstring1))
            {
            qsleep();
            }
            else
            { printf("MODE err \n\r");
            }
            }
           break;
    case 5: //PEEK 
             if(parsetype==0)
            {
            //printf("PEEK \n\r");
            //printf("sa #%s\n\r",xstring1);
            aboo = atol(xstring1);
            printf("Value = 0x%x\n\r",*aboo);
            }
            break;
    case 6: //PEEK 
             if(parsetype==0)
            {
            //printf("POKE \n\r");
            //printf("sa #%s\n\r",xstring1);
            xpoke();
//!            aboo = atol(xstring1);
//!            printf("Value = %x\n\r",*aboo);
            }
            break;        
    case 7: //HELP
           if(parsetype==0)
            {
            printf("------------------------------\n\r");
              printf("Commands UPPER CASE\n\r");
              printf("?<Return Value>, $<Set Value> _ CMD arg(CR)\n\r");
              printf("------------------------------\n\r");
              printf("? VER; VER # <BATT> \n\r");
              printf("$ SDATE; SDATE mm/dd/yr  \n\r");
              printf("$ STIME; STIME hh:mm  \n\r");
              printf("? RTD; RTD; MM/DD/YY HH:MM:SS (24hr). \n\r");
              printf("$ MODE; MODE SLEEP. \n\r");
              printf("? HELP; HELP \n\r");
              printf("------------------------------\n\r");
              if(!strcmp(xstring1,pls))
              {
              printf("$ PEEK; PEEK 0xADD0. \n\r");
              printf("? POKE; POKE 0xADD0:0xF0 \n\r");
              }
            }
           break;
   default:printf("Error\n\r");

            break; }

   return(xret);
}
/////////////////////////////////////
void xsetTime() // time field
{
    int thr, tmn;
              
               xstring2[0] = xstring1[0];
               xstring2[1] = xstring1[1];
               thr = atoi(xstring2);
           wizardTempTime.tm_hour = thr;
                xstring2[0] = xstring1[3];
                xstring2[1] = xstring1[4];
               tmn = atoi(xstring2);
           wizardTempTime.tm_min = tmn;
           wizardTempTime.tm_sec = 1;
           rtc_write(&wizardTempTime);
     
}
/////////////////////////////  Date field
void xsetDate()
{
         int dda, dmo, dyr;
               
               xstring2[0] = xstring1[0];
               xstring2[1] = xstring1[1];
               dda = atoi(xstring2);
            wizardTempTime.tm_mon = dda;
               xstring2[0] = xstring1[3];
               xstring2[1] = xstring1[4];
               dmo = atoi(xstring2);
            wizardTempTime.tm_mday = dmo;
               xstring2[0] = xstring1[6];
               xstring2[1] = xstring1[7];
               dyr = atoi(xstring2);
            wizardTempTime.tm_year = dyr;
          
            wizardTempTime.tm_sec = 1;
            rtc_write(&wizardTempTime);
     
}
void qsleep()
{
         printf("Now in sleep mode \n\r");
          output_low(LED);
          disable_interrupts(INT_TIMER0);
          chan_sel(1);
          sleep();
}
void xpoke()
{
         char *padr;
         int8 pvalx;
               xstring4[0] = xstring1[0];
               xstring4[1] = xstring1[1];
               xstring4[2] = xstring1[2];
               xstring4[3] = xstring1[3];
               xstring4[4] = xstring1[4];
               xstring4[5] = xstring1[5];
               xstring4[6] = (char)0x00;
               padr = atol(xstring4);
         
               xstring2[0] = xstring1[7];
               xstring2[1] = xstring1[8];
               xstring2[2] = xstring1[9];
               xstring2[3] = xstring1[10];
               pvalx = atoi(xstring2);
               // printf(" %4lX : %X \n\r",padr,pvalx);
               *padr = (char)pvalx;
                
}
